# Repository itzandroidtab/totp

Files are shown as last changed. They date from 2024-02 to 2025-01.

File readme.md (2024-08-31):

## Hardware TOTP token
Open source hardware TOTP token. Currently targets the LPC1756, LPC1758 and LPC1759 (with a small change it should also run on the LPC1754). 

### Features
* keys never leave the token after setup
* support for 6 and 8 digit tokens
* enter button types 6/8 digit token using HID keyboard (any device that supports HID keyboards should work)
* supports up to 32 profiles
* rechargable RTC battery
* USB mode to add/delete profiles using a CSV file (supports base32, hex and hex string)
* support to change the RTC calibration values in the settings
* support for setting the time + timezone (currently only GMT)
* 60 seconds screen timeout
* support for different intervals (supports 1 - 180 seconds)

### Images
Images can be found in the project logs at [hackaday](https://hackaday.io/project/194867-hardware-2fa-totp-authenticator)

### TODO
* encrypt profiles
* add support for more than 32 profiles (needs a rework if more profiles are required. The profiles are copied to ram and there is not enough for more at the moment. If we leave them in flash we can store a lot more)
* rework the calibration and time settings screens

### Compiling
TOTP uses [klib](https://github.com/itzandroidtab/klib). This repo can be cloned in the klib project folder. See [build.yml](./.github/workflows/build.yml) for more info on compiling this project.

### Extra
Is intended to be used with [USB dfu bootloader](https://github.com/itzandroidtab/dfu_bootloader). To build without bootloader support remove the `+ 8k` and `- 8k` from line 20 in the `linkerscript.ld` of this project.

The LPC1756 does not have enough ram to hold a full framebuffer (240 * 135 * 2 = 64'800 bytes). To work around this issue, we use 2 smaller framebuffers we alternate between. While one framebuffer is being transferred to the screen using DMA we fill the other.

To make it easier (for me) the whole screen is written to this smaller framebuffer. The pixels that do not fit the framebuffer are thrown away. This does waste CPU cycles but is not limiting the framerate. Filling a full frame with pixels takes around 6 milliseconds. Writing a full frame of framebuffers to the display takes around 11 milliseconds. This limits the maximum framerate to ≈ 85FPS. To get a consistant frame rate there is a limit of 60FPS.

The main screen takes the longest to draw. This is caused by the amount of pixels of the circle it needs to draw. The circle is generated on compile time to work around that the LPC175x family does not have a FPU. These generated pixels use 8640 bytes of flash.

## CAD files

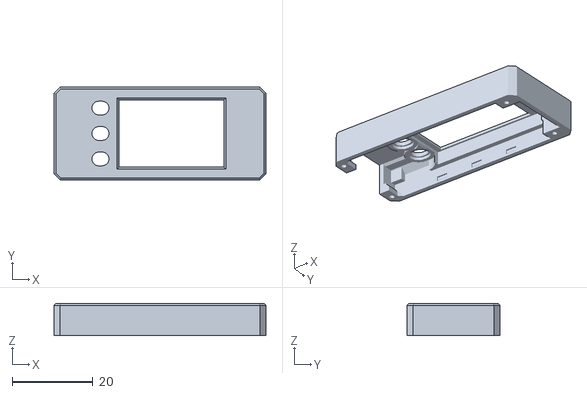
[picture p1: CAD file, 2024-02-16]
hardware/case/top_shell_v3.stl
52.5 x 23.0 x 8.00

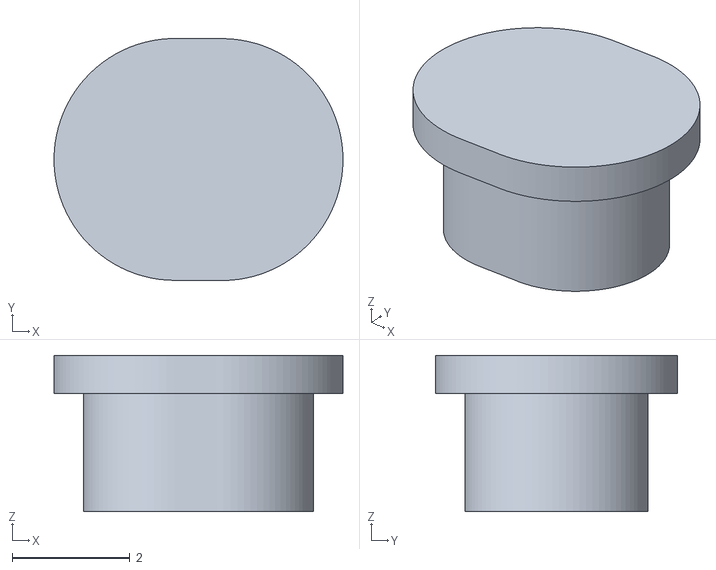
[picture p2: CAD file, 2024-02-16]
hardware/case/button_v3.stl
4.90 x 4.10 x 2.65

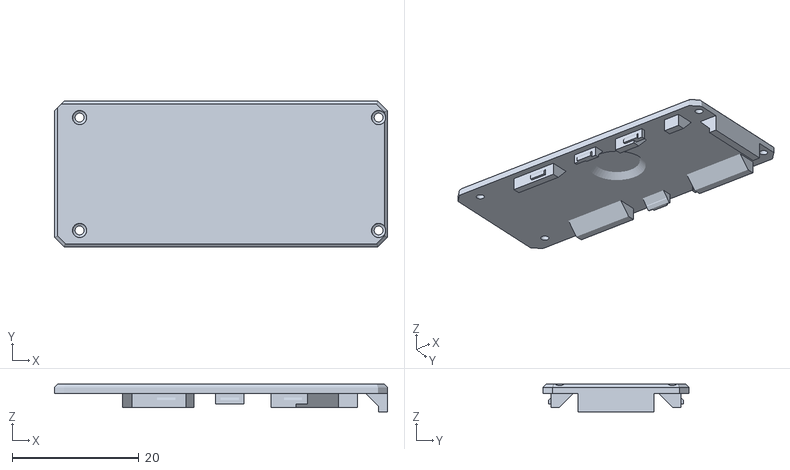
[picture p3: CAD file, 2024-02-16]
hardware/case/back_shell_v3.stl
52.5 x 23.0 x 4.35

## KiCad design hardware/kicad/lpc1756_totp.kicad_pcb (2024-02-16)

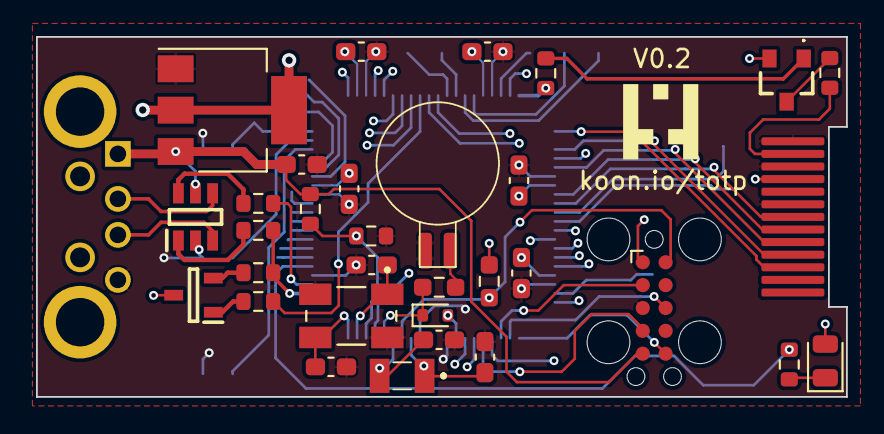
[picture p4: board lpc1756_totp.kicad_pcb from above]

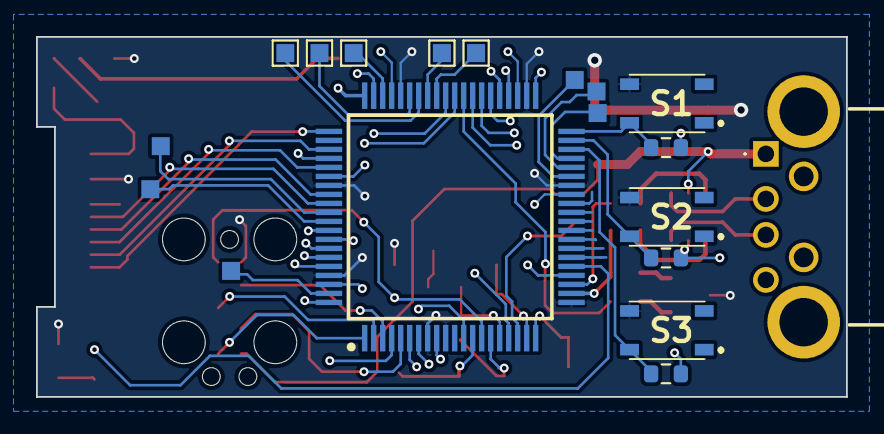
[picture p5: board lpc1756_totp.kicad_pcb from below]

Board: 2 copper layers, 45.0 x 20.0 mm, 40 parts (8 on the bottom side), 38 nets.

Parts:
BT1: MS621FE-FL11E
C1, C2: 10uF; C_0603_1608Metric_Pad1.08x0.95mm_HandSolder
C3, C4, C5, C6: 18pF; C_0603_1608Metric_Pad1.08x0.95mm_HandSolder
C7, C8, C9, C10: 100nF; C_0603_1608Metric_Pad1.08x0.95mm_HandSolder
D1: IP4234CZ6,125; SOP95P275X110-6N
D2: LED; LED_0805_2012Metric
D3: D_Schottky; D_SOD-523
IC1: LPC1756FBD80,551; QFP50P1400X1400X160-80N
J1: MC32603
Q1: BC856A,215; SOT95P230X110-3N
Q2: RN2425_TE85L,F_; RN2425TE85LF
R1, R2: 33; R_0603_1608Metric
R3, R6: 300; R_0603_1608Metric
R4: 750; R_0603_1608Metric
R5: 1000; R_0603_1608Metric
R7: 1K; R_0603_1608Metric
R8: 1.5K; R_0603_1608Metric
R9, R11, R13, R14: 1k; R_0603_1608Metric
R10: 10K; R_0603_1608Metric_Pad0.98x0.95mm_HandSolder
R12: 1.8K; R_0603_1608Metric_Pad0.98x0.95mm_HandSolder
S1, S2, S3: PTS810SJK250SMTRLFS; PTS810SJG250SMTRLFS
U1: st7735_mini_lcd; ST7735
U2: AMS1117-3.3; SOT-223-3_TabPin2
U3: TC2050; Tag-Connect_TC2050-IDC-FP_2x05_P1.27mm_Vertical
Y1: ABS07-32.768KHZ-T; ABS0716632768KHZT
Y2: ABM3B-12.000MHZ-B2-T; XTAL_ABM3B-12.000MHZ-B2-T

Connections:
+3.3V: C2.1, C7.1, C8.1, C9.1, C10.1, D2.2 (A), D3.2 (A), IC1.8 (VDDA), IC1.10 (VREFP), IC1.21 (VDD(3V3)_1), IC1.34 (VDD(REG)(3V3)_1), IC1.42 (VDD(3V3)_2), IC1.56 (VDD(3V3)_3), IC1.67 (VDD(REG)(3V3)_2), IC1.77 (VDD(3V3)_4), Q1.3, Q2.2, R10.1, S1.4, S2.4, S3.4, U1.10 (VDD), U2.2 (VO), U3.1 (VTref)
+5V: C1.1, D1.5 (VCC), J1.1, R4.1, U2.3 (VI), U3.5 (5V-Supply)
/CPU/RSTN: IC1.14 (~RESET), R10.2, U3.10 (nReset)
/CPU/XTAL_RTC_X1: C3.1, IC1.13 (RTCX1), Y1.1
/CPU/XTAL_RTC_X2: C4.1, IC1.15 (RTCX2), Y1.2
/CPU/XTAL_X1: C5.1, IC1.19 (XTAL1), Y2.1
/CPU/XTAL_X2: C6.1, IC1.20 (XTAL2), Y2.3
/USB/USB_D+: D1.3 (ESD_I/O_CH_1_2), J1.3
/USB/USB_D-: D1.4 (ESD_I/O_CH_2_1), J1.2
/User/LCD_B: Q2.3, R6.2
D+: IC1.22 (P0[29]/USB_D+), R2.2, R8.1
D-: IC1.23 (P0[30]/USB_D-), R1.2
GND: BT1.2 (-), C1.2, C2.2, C3.2, C4.2, C5.2, C6.2, C7.2, C8.2, C9.2, C10.2, D1.2 (VDD), IC1.9 (VSSA), IC1.12 (VREFN), IC1.24 (VSS_1), IC1.33 (VSS_2), IC1.43 (VSS_3), IC1.57 (VSS_4), IC1.66 (VSS_5), IC1.78 (VSS_6), J1.4, R5.2, R11.1, R13.1, R14.1, U1.8 (GND), U1.11 (LEDK), U1.13 (GND), U2.1 (GND), U3.3 (GND), Y2.2 (GND), Y2.4 (GND)
LCD_BLK: IC1.60 (P2[0]/PWM1[1]/_TXD1), R9.2
LCD_CS: IC1.69 (P1[15]/_ENET_REF_CLK), U1.7 (CS)
LCD_DC: IC1.65 (P4[28]/RX_MCLK/_MAT2[0]/TXD3), U1.5 (DC)
LCD_MOSI: IC1.61 (P0[9]/I2STX_SDA/_MOSI1/MAT2[3]), U1.3 (MOSI)
LCD_RST: IC1.68 (P4[29]/TX_MCLK/_MAT2[1]/RXD3), U1.6 (RST)
LCD_SCK: IC1.63 (P0[7]/I2STX_CLK/_SCK1/MAT2[1]), U1.4 (SCK)
unnamed: BT1.1 (+), R12.2
unnamed: D1.1 (ESD_I/O_CH_1_1), R2.1
unnamed: D1.6 (ESD_I/O_CH_2_2), R1.1
unnamed: D2.1 (K), R3.2
unnamed: Q1.1, R7.1
unnamed: Q1.2, R8.2
unnamed: Q2.1, R9.1
unnamed: R6.1, U1.12 (LEDA)
TCK: IC1.5 (TCK/SWDCLK), U3.4 (TCK)
TDI: IC1.2 (TDI), U3.8 (TDI)
TDO: IC1.1 (TDO/SWO), U3.6 (TDO)
TMS: IC1.3 (TMS/SWDIO), U3.2 (TMS)
USB_ACT: IC1.25 (P1[18]/_USB_UP_LED/_PWM1[1]/_CAP1[0]), R3.1
USB_CONNECT: IC1.49 (P2[9]/_USB_CONNECT/_RXD2), R7.2
USER_IO0: IC1.40 (P0[11]/RXD2/_SCL2/MAT3[1]), R11.2, S1.2
USER_IO1: IC1.39 (P0[10]/TXD2/_SDA2/MAT3[0]), R13.2, S2.2
USER_IO2: IC1.38 (P0[1]/TD1/RXD3/_SCL1), R14.2, S3.2
VBAT: D3.1 (K), IC1.16 (VBAT), R12.1
VBUS: IC1.18 (P1[30]/VBUS/_AD0[4]), R4.2, R5.1

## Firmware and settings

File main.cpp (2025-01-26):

#include <klib/klib.hpp>
#include <klib/stream.hpp>

#include "ui/screen.hpp"
#include "ui/totp.hpp"
#include "ui/splash.hpp"
#include "ui/settings.hpp"
#include "ui/numeric_popup.hpp"
#include "ui/popup.hpp"
#include "ui/time.hpp"
#include "ui/timezone.hpp"
#include "ui/calibration.hpp"
#include "ui/config.hpp"
#include "ui/mouse.hpp"

#include "button.hpp"
#include "storage.hpp"

#include <io/ssp.hpp>
#include <io/rtc.hpp>
#include <io/dma.hpp>
#include <io/usb.hpp>
#include <io/system.hpp>
#include <io/flash.hpp>

#include <klib/usb/device/mass_storage.hpp>
#include <klib/usb/device/keyboard.hpp>
#include <klib/usb/device/mouse.hpp>

#include <klib/hardware/display/st7789.hpp>
#include <klib/graphics/framebuffer.hpp>
#include <klib/graphics/framebuffer_modifier.hpp>

#include <klib/filesystem/virtual_fat.hpp>

namespace target = klib::target;

constexpr static klib::time::ms screen_timeout = 60'000;
constexpr static uint32_t fps_frametime = (1'000'000) / 60;

// using for the ssp (spi port)
using ssp = klib::target::io::ssp<klib::target::io::periph::lqfp_80::ssp1<>>;

// using for the display io
using blk = klib::target::io::pin_out<klib::target::pins::package::lqfp_80::p60>;
using rst = klib::target::io::pin_out<klib::target::pins::package::lqfp_80::p68>;
using dc = klib::target::io::pin_out<klib::target::pins::package::lqfp_80::p65>;
using cs = klib::target::io::pin_out<klib::target::pins::package::lqfp_80::p69>;

int main() {
    // using for the rtc clock
    using rtc_periph = target::io::periph::rtc0;
    using rtc = target::io::rtc<rtc_periph>;

    // using for the button pin
    using button0 = target::io::pin_in<target::pins::package::lqfp_80::p40>;
    using button1 = target::io::pin_in<target::pins::package::lqfp_80::p39>;
    using button2 = target::io::pin_in<target::pins::package::lqfp_80::p38>;

    using fat_helper = menu::detail::fat_helper;

    // using for the usb driver/device
    using usb_keyboard = target::io::usb<target::io::periph::lqfp_80::usb0, klib::usb::device::keyboard_hid<4>>;
    using usb_mouse = target::io::usb<target::io::periph::lqfp_80::usb0, klib::usb::device::mouse_hid<4>>;
    using usb_massstorage = target::io::usb<target::io::periph::lqfp_80::usb0, 
        klib::usb::device::mass_storage<fat_helper>
    >;
    
    // init all the display hardware and the buttons
    ssp::init<klib::io::spi::mode::mode3, 48'000'000, klib::io::spi::bits::bit_8, true>();

    // init the io needed for the display
    blk::init();
    rst::init();
    dc::init();
    cs::init();

    // enable the backlight and clear the chip select to 
    // the display so we can talk to it
    blk::set<false>();
    cs::set<false>();

    // init the dma engine
    using dma_periph = target::io::periph::dma0;
    using dma = target::io::dma<dma_periph>;
    dma::init<std::endian::big>();

    // create the dma channels
    using dma_tx = target::io::dma_channel<dma_periph, 0, klib::io::dma::memory, ssp>;
    using dma_rx = target::io::dma_channel<dma_periph, 1, ssp, klib::io::dma::memory>;

    dma_tx::init();
    dma_rx::init();

    using display = klib::hardware::display::st7789_dma<dma_tx, dma_rx, ssp, dc, rst, klib::graphics::mode::rgb565, 240, 135, 40, 52>;

    // init the buttons
    button0::init();
    button1::init();
    button2::init();

    // check if any of the buttons is pressed
    const bool flipped = button0::get() || button2::get();

    // initialize the display in the correct orientation. We flip the screen
    // if any of the buttons are pressed while we are powered on
    if (flipped) {
        display::init<true, false, klib::graphics::orientation::landscape, false, true>();
    }
    else {
        display::init<true, false, klib::graphics::orientation::landscape, true, false>();
    }

    // clear any data left in the fifo register to prevent 
    // stalls when we use the dma later
    ssp::clear_rx_fifo();

    // create the framebuffers
    constexpr static uint32_t move_height = 10;
    using fb_t = klib::graphics::movable_framebuffer<display, display::mode, 0, 0, display::width, move_height, std::endian::big>;

    // this needs to be static to move it to RAM1. 
    static std::array<fb_t, 2> framebuffer __attribute__ ((section(".framebuffer"))) = {fb_t(), fb_t()};

    // init all the framebuffers
    for (auto& fb: framebuffer) {
        fb.init();
    }

    // setup the usb pll
    target::io::system::clock::set_usb<12'000'000>();

    // using for writing to flash
    using flash = target::io::flash;

    // using for the storage
    using storage = storage::storage<flash>;

    // create the popup first as some other screens use it
    menu::numeric_popup<fb_t> numeric_popup = {};
    menu::popup<fb_t> string_popup = {};

    // setup the first state. We initialize everything 
    // except the screen in the splash screen. This speeds
    // up the boot time and will show the splash screen
    // until we are done initializing. 
    menu::splash<fb_t, storage, rtc, usb_keyboard> splash = {};
    menu::totp<fb_t, storage, rtc, rtc_periph, usb_keyboard> totp = {};
    menu::settings<fb_t> settings = {};
    menu::time<fb_t, rtc_periph, rtc> time(numeric_popup);
    menu::timezone<fb_t, rtc_periph> timezone(numeric_popup);
    menu::calibration<fb_t, rtc_periph> calibration(numeric_popup, string_popup);
    menu::config<
        fb_t, storage, fat_helper, 
        usb_keyboard, usb_massstorage
    > config = {};
    menu::mouse<fb_t, usb_keyboard, usb_mouse> mouse = {};

    // array with all the app screens
    menu::screen<fb_t> *const screens[] = {
        &splash,
        &totp,
        &settings,
        &time,
        &timezone,
        &calibration,
        &config,
        &mouse,
        &numeric_popup,
        &string_popup,
    };

    // get the current screen
    uint8_t previous_screen = static_cast<uint8_t>(menu::screen<fb_t>::get());

    // call activate on the first screen
    screens[previous_screen]->activate(menu::screen_id::splash);

    // current active framebuffer
    uint8_t current_framebuffer = 0;

    // last time the user pressed a button for the screen timeout
    auto last_pressed_time = klib::io::systick<>::template get_runtime();

    // get the previous time for the delta
    auto previous_time = klib::io::systick<>::get_runtime<klib::time::us>();

    // timing for the buttons. To keep track on how long a 
    // button is pressed. We mark everything with the pressed
    // marker to make sure we do not enter a menu straight 
    // away
    std::array<klib::time::us, 3> button_timing = {
        input::pressed_marker, input::pressed_marker, 
        input::pressed_marker
    };

    while (true) {
        // get the current screen
        const uint8_t current_screen = static_cast<uint8_t>(menu::screen<fb_t>::get());

        // get the current time
        const auto current_time = klib::io::systick<>::template get_runtime<klib::time::us>();

        // get the buttons
        input::buttons buttons = input::get_state(
            current_time - previous_time, flipped, button_timing, 
            {button0::get(), button1::get(), button2::get()}
        );

        // flag if we have reached the screen timeout
        const bool timeout = klib::io::systick<>::get_runtime() > (last_pressed_time + screen_timeout);

        // check if we have pressed any button
        if (is_pressed(buttons.up) || is_pressed(buttons.enter) || is_pressed(buttons.down)) {
            // check if we need to enable the backlight again
            if (timeout) {
                // turn on the backlight
                blk::set<false>();

                // prevent any of the buttons from triggering when we turn on the backlight
                buttons = {input::state::no_change, input::state::no_change, input::state::no_change};
            }

            // update the last time we pressed the buttons
            last_pressed_time = klib::io::systick<>::get_runtime();
        }
        else if (timeout) {
            // turn off the backlight
            blk::set<true>();
        }

        // check if we have switched screens
        if (current_screen != previous_screen) {
            // deactivate the previous screen
            screens[previous_screen]->deactivate(
                static_cast<menu::screen_id>(current_screen)
            );

            // activate the current screen
            screens[current_screen]->activate(
                static_cast<menu::screen_id>(previous_screen)
            );

            // set the current screen as the previous screen for a next change
            previous_screen = current_screen;

            // clear the delta for the current screen
            previous_time = current_time;
        }

        // run the correct screen
        screens[current_screen]->main(current_time - previous_time, buttons);

        // draw the screen alternating the framebuffers
        for (uint32_t i = 0; i < display::height; i += move_height) {
            // call the on_draw
            screens[current_screen]->draw(
                framebuffer[current_framebuffer], {0, i}
            );

            // wait until the previous segment is done until we update it
            while (dma_tx::is_busy()) {
                // wait
            }

            // after the dma signals it is done we still have data in the
            // ssp fifo. Wait until we are done with that as well before
            // we write new data
            while (ssp::is_busy()) {
                // wait
            }

            // clear any data left in the fifo register to prevent 
            // stalls when we use the dma later
            ssp::clear_rx_fifo();

            // flush the framebuffer to the display
            framebuffer[current_framebuffer].flush(klib::vector2u(0, i));

            // swap the framebuffer we are using
            current_framebuffer ^= 1;
        }

        // update the previous time
        previous_time = current_time;

        const auto end_time = klib::io::systick<>::template get_runtime<klib::time::us>();

        // we try to target around 60 fps
        if ((end_time - current_time).value < fps_frametime) {
            // wait the remaining time
            klib::delay(klib::time::us(fps_frametime - (end_time - current_time).value));
        }
    }
}

namespace fault {
    /**
     * @brief Available fault types
     * 
     */
    enum class type {
        // vector table entries
        hardfault = 3,
        memfault = 4,
        busfault = 5,
        usagefault = 6,

        // other fault types. Note: value is outside the 
        // vector table range
        functioncall = 256,
    };

    /**
     * @brief Hardfault handler that shows a error on the screen
     * this function initializes the hardware of the displays and
     * uses a direct framebuffer to prevent using too much ram and
     * causing another issue
     * 
     * @note noinline attribute is to prevent the compiler from 
     * inlining this in the naked function. When that happens
     * the error screen does not popup for some reason. 
     * 
     * TODO: figure out why this happens
     * 
     * @param fault 
     * @param stack 
     */
    void __attribute__ ((noinline)) hardfault_handler_impl(const type fault, const uint32_t stack) {
        // create a display without dma
        // TODO: make this sync up with the other display somehow
        using display = klib::hardware::display::st7789<ssp, dc, rst, klib::graphics::mode::rgb565, 240, 135, 40, 52>;

        // reinit the hardware needed to show something on the display
        ssp::template init<klib::io::spi::mode::mode3, 48'000'000, klib::io::spi::bits::bit_8, true>();

        // clear the rx fifo just in case there is data left in the fifo after the crash
        ssp::clear_rx_fifo();

        // init the io needed for the display
        blk::init();
        rst::init();
        dc::init();
        cs::init();

        // enable the backlight and clear the chip select to 
        // the display so we can talk to it
        blk::set<false>();
        cs::set<false>();

        // just init the screen, no need to flip it
        display::init<true, false, klib::graphics::orientation::landscape, true, false>();

        // write directly to the display
        using framebuffer_t = klib::graphics::direct_framebuffer<display, true, 0, 0, display::width, display::height, std::endian::little>;
        framebuffer_t framebuffer;

        // initialize the framebuffer
        framebuffer.init();

        // clear the framebuffer
        framebuffer.clear(klib::graphics::yellow);

        // write the framebuffer to the display
        framebuffer.flush();

        // fonts to display something on the screen
        using small_font = klib::graphics::ascii_font_8x8;
        using small_text = klib::graphics::string<small_font>;
        using large_font = klib::graphics::ascii_font_16x16;
        using large_text = klib::graphics::string<large_font>;

        constexpr static char title[] = "Crash detected";

        // write we detected a crash
        large_text::draw(framebuffer, title, 
            klib::vector2i{
                (240 - static_cast<int32_t>(klib::string::strlen(title) * large_text::font::width)) / 2, 3
            }, klib::graphics::black, klib::graphics::transparent
        );

        // string to show
        char buffer[32] = {};

        switch (fault) {
            case type::functioncall: 
                klib::string::strcpy(buffer, "Function fault");
                break;
            default:
                // check if we have a stack overflow
                if ((stack <= reinterpret_cast<uint32_t>(&__stack_start))|| (stack > reinterpret_cast<uint32_t>(&__stack_end))) {
                    // copy the string to the buffer
                    klib::string::strcpy(buffer, "Stack overflow SP:");

                    // copy the stack we crashed on to the buffer
                    klib::string::itoa<klib::base::HEX>(stack, buffer + klib::string::strlen(buffer));
                }
                else {
                    // copy the string to the buffer
                    klib::string::strcpy(buffer, "Unknown fault:");
                    klib::string::itoa(static_cast<uint32_t>(fault), buffer + klib::string::strlen(buffer));
                }
                break;
        }

        // check if we need to show the additional line
        if (klib::string::strlen(buffer)) {
            // draw the stack pointer we detected
            small_text::draw(
                framebuffer, buffer,
                klib::vector2i{
                    (240 - static_cast<int32_t>(klib::string::strlen(buffer) * small_text::font::width)) / 2, 40
                }, 
                klib::graphics::black, klib::graphics::transparent
            );
        }

        // message to display
        constexpr static char message[] = 
            "Unplug authenticator\nand replug USB to restart.\n\nIf you keep seeing this error\n"
            "please report this error to:\n\nkoon.io/totp\n";
        
        uint32_t start = 0;
        uint32_t count = 0;

        // display the strings
        for (uint32_t i = 0; i < klib::string::strlen(message); i++) {
            if (message[i] != '\n') {
                continue;
            }

            // draw the text
            small_text::draw(
                framebuffer, 
                &message[start], (i - start),
                klib::vector2i{
                    (240 - static_cast<int32_t>((i - start) * small_text::font::width)) / 2,
                    static_cast<int32_t>(56 + (small_text::font::height * count))
                }, 
                klib::graphics::black, klib::graphics::transparent
            );

            // update the start
            start = i + 1;
            count++;
        }

        // write the framebuffer to the display
        framebuffer.flush();
    }
}

/**
 * @brief Hardfault handler. Called when we crashed
 * 
 */
void __attribute__((__noreturn__, __naked__)) hardfault_handler() {
    // get the current sp register. Note: this cannot be on the stack
    // the stack might not be valid at this point
    const uint32_t sp = __get_MSP();

    // make sure we have a valid stack pointer. At this point we are gonna 
    // overwrite everything as we cannot recover anyway. (the heap is at
    // the end of everything)
    __set_MSP(reinterpret_cast<uint32_t>(&__heap_end));

    // call the hardfault implementation after we have changed the stack pointer
    fault::hardfault_handler_impl(static_cast<fault::type>(__get_IPSR()), sp);

    // wait until the user unplugs
    while (true) {
        // do nothing
    }
}

// implement the throw_bad_function_call so we can use std::function
namespace std {
    void __throw_bad_function_call() { 
        // call the hardfault implementation if we ever get here
        fault::hardfault_handler_impl(
            fault::type::functioncall, __get_MSP()
        );

        while(true) {
            // do nothing when we have a bad function call
        }
    }; 
}

/**
 * @brief Constructor that gets called before main is called. This 
 * constructor registers the hardfault_handler as the callback for
 * every fault we can detect
 * 
 */
void __attribute__((__constructor__)) fault_startup() {
    // register the hard fault handler for all the faults we 
    // can detect before we run main. This is so we can catch 
    // everything main does
    target::irq::register_irq<target::irq::arm_vector::hard_fault>(hardfault_handler);
    target::irq::register_irq<target::irq::arm_vector::memory_managagement_fault>(hardfault_handler);
    target::irq::register_irq<target::irq::arm_vector::bus_fault>(hardfault_handler);
    target::irq::register_irq<target::irq::arm_vector::usage_fault>(hardfault_handler);
}

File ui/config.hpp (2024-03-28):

#pragma once

#include <cstring>
#include <optional>

#include <klib/filesystem/virtual_fat.hpp>
#include <klib/delay.hpp>
#include <klib/string.hpp>
#include <klib/crypt/base32.hpp>

#include "screen.hpp"

namespace menu::detail {
    const char* strnstr(const char *haystack, const char *needle, size_t len) {
        const size_t needle_len = klib::string::strlen(needle);

        if (!needle_len) {
            return haystack;
        }

        for (uint32_t i = 0; i <= (len - needle_len); i++) {
            if ((haystack[0] == needle[0]) && (0 == std::strncmp(haystack, needle, needle_len))) {
                return haystack;
            }

            haystack++;
        }

        return nullptr;
    }

    class fat_helper {
    public:
        // fat filesystem
        using filesystem = klib::filesystem::virtual_fat<fat_helper, 16, (static_cast<uint32_t>(1) * 1024 * 1024), 16, 1>;

        /**
         * @brief Functions required for the filesystem. These functions will 
         * be called when something changes in the filesystem (other than the
         * already existing files)
         * 
         */

        static void on_delete(const uint32_t index, const klib::filesystem::detail::directory& old) {
            // do nothing
        }

        static void on_create(const uint32_t index, const klib::filesystem::detail::directory& n) {
            // do nothing
        }

        static void on_change(const uint32_t index, const klib::filesystem::detail::directory& old, const klib::filesystem::detail::directory& n) {
            // do nothing
        }

        static void file_handler(const uint32_t offset, const uint8_t *const data, const uint32_t sectors) {
            // do nothing
        }

    public:
        /**
         * @brief Functions required for the mass storage interface. Connects 
         * the virtual filesystem and the interface together
         * 
         */

        /**
         * @brief Init the memory
         * 
         */
        static void init() {
            // do nothing here
        }

        /**
         * @brief Start the memory
         * 
         */
        static void start() {
            // nothing to do here
        }

        /**
         * @brief Stop any pending transaction and flush to disk
         * 
         * @return true 
         * @return false 
         */
        static bool stop() {
            return true;
        }

        /**
         * @brief Return if the memory is ready
         * 
         * @return true 
         * @return false 
         */
        static bool ready() {
            return true;
        }

        /**
         * @brief Returns if the device can be removed from the host
         * 
         * @return true 
         * @return false 
         */
        static bool can_remove() {
            // return the device can be removed
            return true;
        }

        /**
         * @brief Returns the size of the memory device in bytes
         * 
         * @return uint32_t 
         */
        static uint32_t size() {
            // return the filesystem size
            return filesystem::size();
        }

        /**
         * @brief Returns if the drive is writable
         * 
         * @return true 
         * @return false 
         */
        static bool is_writable() {
            return true;
        }

        /**
         * @brief Read a sector. Can read up to SectorSize of bytes 
         * at once (without crossing a sector boundry)
         * 
         * @param data 
         * @param address 
         * @param size 
         * @return true 
         * @return false 
         */
        static bool read(uint8_t *const data, const uint32_t address, const uint16_t size) {
            // change the address and size to sector sizes and give it to the virtual filesystem
            filesystem::read(address / filesystem::sector_size, data, size / filesystem::sector_size);

            // return we are good
            return true;
        }

        /**
         * @brief Write to a sector. Can write up to SectorSize of bytes 
         * at once (without crossing a sector boundry)
         * 
         * @param data 
         * @param address 
         * @param size 
         * @return true 
         * @return false 
         */
        static bool write(uint8_t *const data, const uint32_t address, const uint16_t size) {
            // change the address and size to sector sizes and give it to the virtual filesystem
            filesystem::write(address / filesystem::sector_size, data, size / filesystem::sector_size);

            // return we are good
            return true;
        }
    };
}
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

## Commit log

2024-01-26 bugfix big config files
    [config.hpp]
2024-02-16 updated linkerscript to show correct sizes + added profiles location (for lpc1756)
    [main.cpp]
2024-02-16 added STL files for the case
    [back_shell_v3.stl, button_v3.stl, top_shell_v3.stl]
2024-02-16 added kicad files
    [cpu.kicad_sch, lcd.kicad_sch, lpc1756_totp.kicad_pcb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]
2024-02-25 changed cal options to have text fields instead of 0 and 1 + bugfix going to previous screen
    [main.cpp]
2024-03-07 Storage rework to load from linkerscript (#1)
    * made storage load from profile section instead of hardcoded
    * cleanup old hardcoded values
    * Added note for profiles in linkerscript
    [main.cpp]
2024-03-24 moved framebuffer to seperate section
2024-03-24 bugfix current out of range when deleting entries
    [totp.hpp]
2024-03-24 bugfix time not updating straight away when interval is different
    [totp.hpp]
2024-03-24 bugfix circle only updating on the second mark + made circle less jittery
    [totp.hpp]
2024-03-24 added a error screen if a hardfault occurs
    [main.cpp]
2024-03-24 bugfix rtc time updating last runtime when the interval changed
    [totp.hpp]
2024-03-24 bugfix showing old messages when entering config
    [config.hpp]
2024-03-28 bugfix not clearing framebuffer on all screens
    [config.hpp]
2024-03-28 reworked menu for better settings screen
    [menu.hpp]
2024-03-29 bugfix going out of bounds in the menu
    [menu.hpp]
2025-01-26 Updated DMA template parameter to std::endian
